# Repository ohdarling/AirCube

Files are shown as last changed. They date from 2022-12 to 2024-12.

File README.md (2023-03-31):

# AirCube 空气检测站

[English Version](README_EN.md)

AirCube 是一个开源的环境状态监测设备，可以监测各种环境状态，例如温度、湿度、二氧化碳浓度、PM 2.5 浓度等，还可以与 Domoticz、Home Assistant 等智能家居系统集成，建立家庭环境数据监测系统。

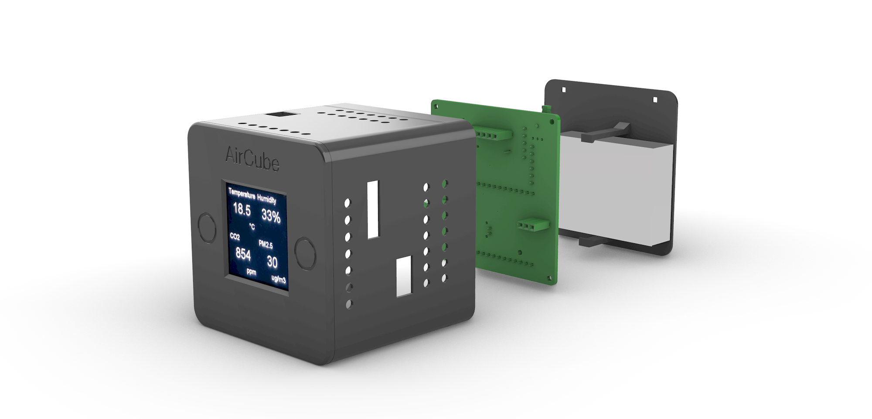
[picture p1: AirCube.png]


## 功能列表

* 概览页面，可以直观查看各种环境数据的当前数值，例如当前温度、湿度、PM 2.5 以及二氧化碳浓度
* 左右键切换传感器详情界面，可以查看具体细分项数值，例如 PM 1，PM 10 等
* 各项数据的历史趋势数据，通过记录过去 12 小时的数据并通过图表展示环境数据的变化趋势
* 特定传感器的详情数据，例如攀藤 PMS5003 可以同时检测 PM 1.0、PM 2.5、PM 10 浓度，在概览页面无法展示完全，就可以在详情页面展示出来
* 设备信息界面，可以展示当前设备的名称、Wi-Fi 连接情况、运行时间等基础信息
* 数据上报能力，可以通过 MQTT 将数据上报到 Domoticz 或 Home Assistant
* 批量部署能力，通过脚本批量部署设备固件

## 更新日志

* 2023.03.31
  * 禁用 MQTT 无法连接时自动重启，防止未配置 MQTT Broker 时 AirCube 定时重启
  
* 2023.02.24
  * 与小米温湿度传感器对比后，BME280 温度校正 -2，湿度 +10
  * 添加重启功能，长按右键 5 秒以上，会重启 AirCube
  * 添加 CO2 传感器校准功能，长按左键 5 秒以上，开启 MH-Z19 或 SenseAir S8 校准功能，校准前请将 AirCube 在室外放置运行 20 分钟以上
  * 使用自定义组件读取 BME280 数据，避免 ESPHome 初始化失败的问题

## 目录结构

* 3D_Model - 设备外壳 3D 模型文件，可以通过 FDM 类型 3D 打印机打印
  * AirCube_Back.stl - 后盖
  * AirCube_Eink.stl - 使用 E-ink 屏幕时的外壳模型
  * AirCube_Eink_Stand.stl - 使用 E-ink 屏幕时的屏幕支架
  * AirCube_LCD.stl - 使用 LCD 屏幕时的外壳模型
  * AirCube_LCD_Stand.stl - 使用 LCD 屏幕时的屏幕支架

* Firmware - 基于 ESPHome 的设备固件，因传感器造型可变化，未编译成二进行，可以自行编译
* Hardware - 包含用于制造 PCB 的 Gerber 文件和原理图

## PCB

PCB 尺寸为 6cm x 6cm，四角安装孔直径为 2mm。

* PCB 正面为屏幕及触摸按钮安装位置。

* PCB 底面为传感器及 NodeMCU 安装位置，目前版本预留了 IR、433MHz 以及电源接头，但并未使用。

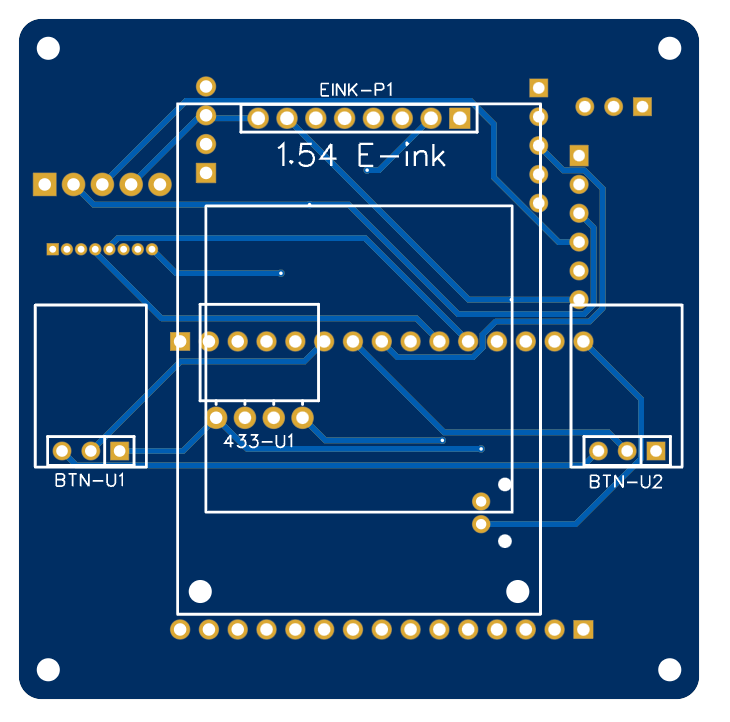
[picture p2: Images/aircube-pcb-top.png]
aircube-pcb-top
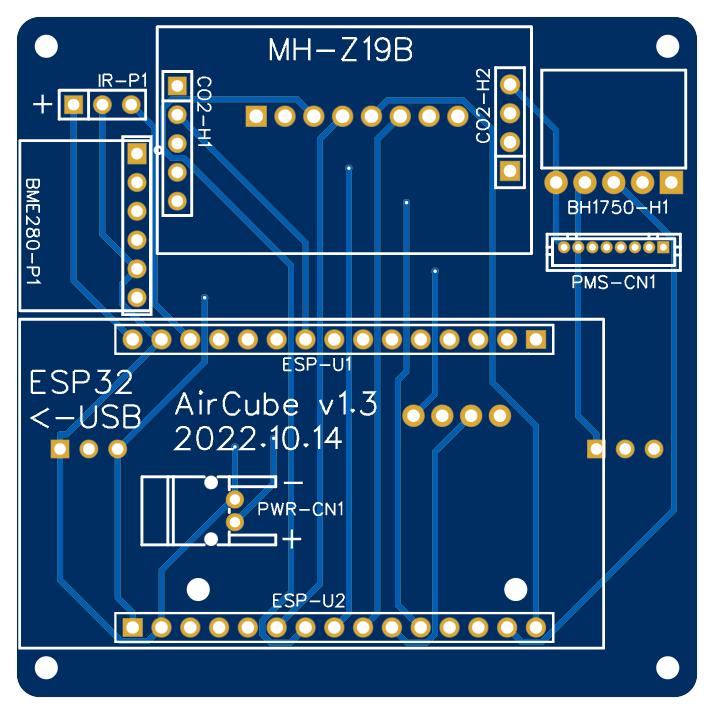
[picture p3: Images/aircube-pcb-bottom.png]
aircube-pcb-bottom


## 元件选型

| 图片 | 类型 | 型号 | 价格（元） | 说明 |
| --- | --- | --- | --- | --- |
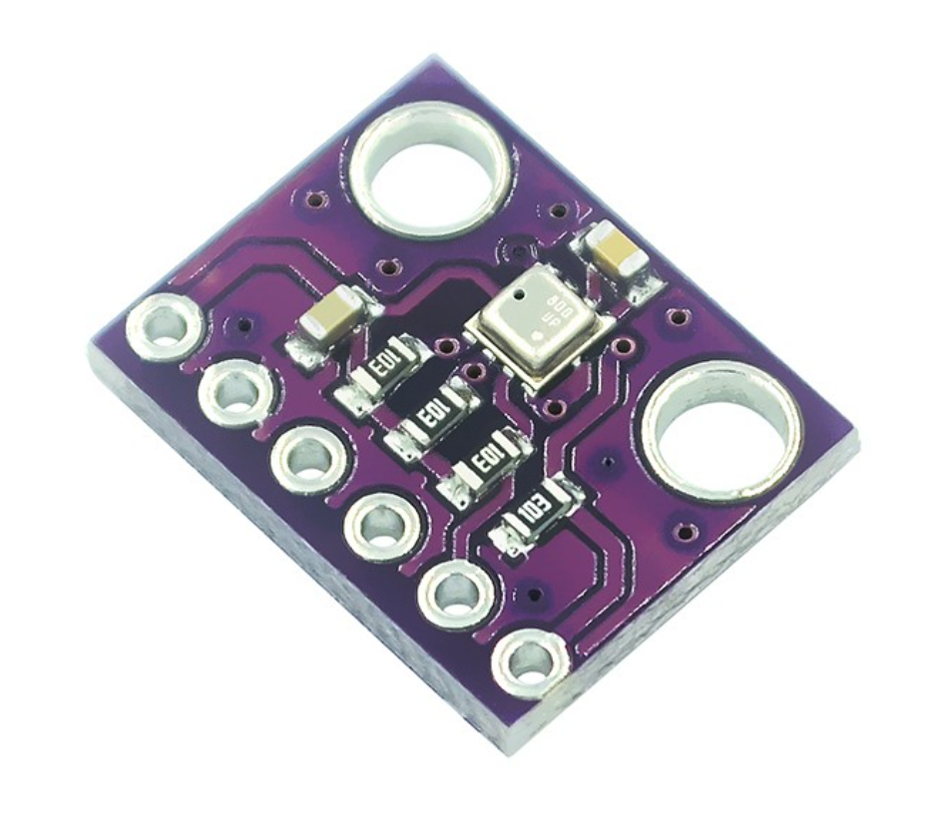
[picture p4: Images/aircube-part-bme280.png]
BME280
|  | 温湿度 | BME280 或 SHT31 | 22 | 其中 BME280 还额外支持压强检测，同时支持这两种传感器主要是因为它们的引脚顺序相同，可以替换使用。 |
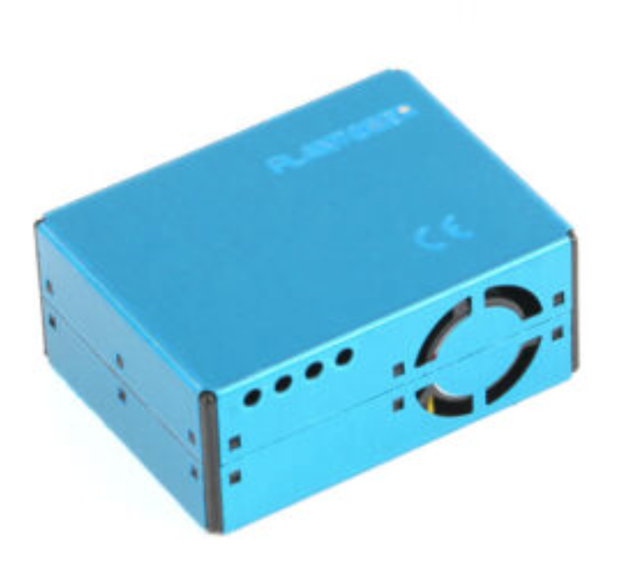
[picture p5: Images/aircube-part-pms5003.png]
PMS5003
|  | 颗粒物浓度 | 攀藤 PMS5003 | 70 | 支持 PM 1.0、PM 2.5、PM 10 三种颗粒物浓度检测，以及 PMS5003ST，额外增加了甲醛浓度检测。另外 PMS7003 虽然同样可以使用，但是因为需要额外转接板，不能直接使用 1.25mm 8P 连接线，因此并不推荐。 |
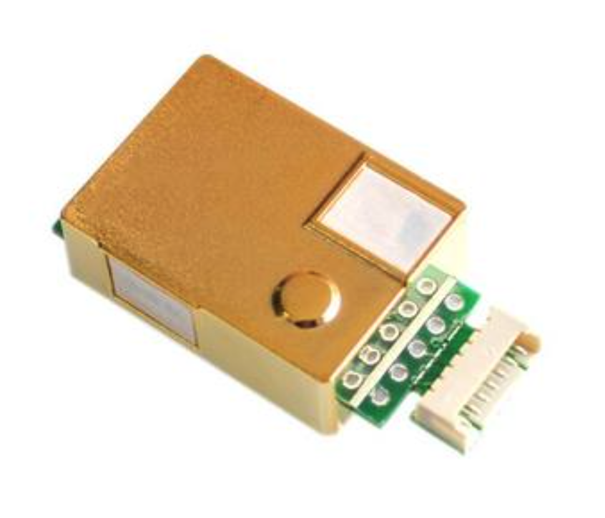
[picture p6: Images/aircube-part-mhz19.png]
MH-Z19B
|  | 二氧化碳浓度 | MH-Z19B | 120 | 可以检测 400-5000 ppm 范围的二氧化碳浓度，当然也可以采用 SenseAir S8 传感器，它们的引脚位置和定义都完全一致。 |
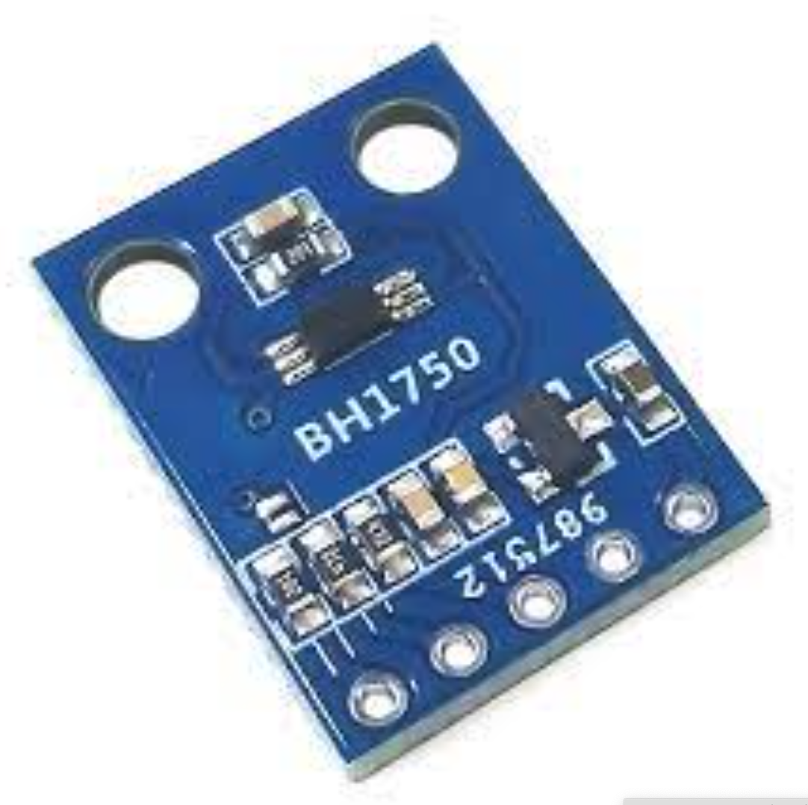
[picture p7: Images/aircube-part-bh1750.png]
BH1750
|  | 光照强度 | BH1750 | 4 | 如果使用光敏电阻还需要额外换算，还是直接采用传感器更简单直接。 |
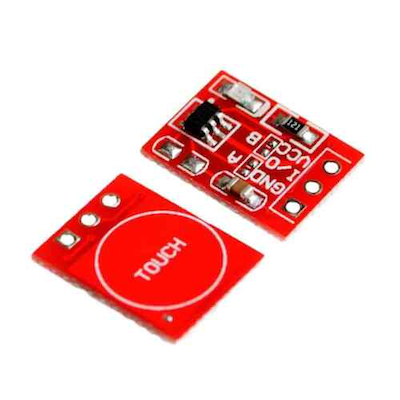
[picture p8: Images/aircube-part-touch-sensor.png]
TTP223
|  | 触摸按钮 | TTP223 | 0.3 | 这个模块触摸感应距离大，可以隔着外壳完成触摸操作，用来切换信息页。 |
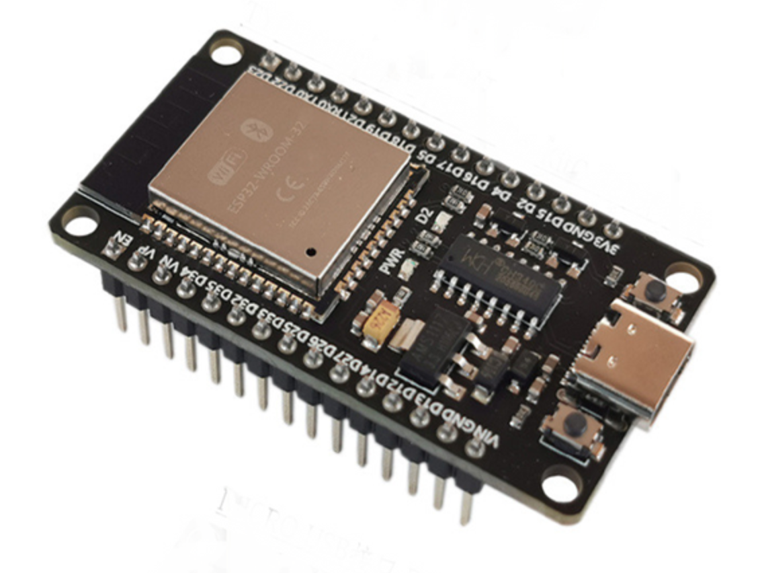
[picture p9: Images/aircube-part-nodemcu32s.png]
NodeMCU-32S
|  | 单片机 | NodeMCU-32S | 22 | 直接选用常见的 NodeMCU-32S 开发板，价格便宜，还可以直接给传感器提供 3.3V 供电。 |
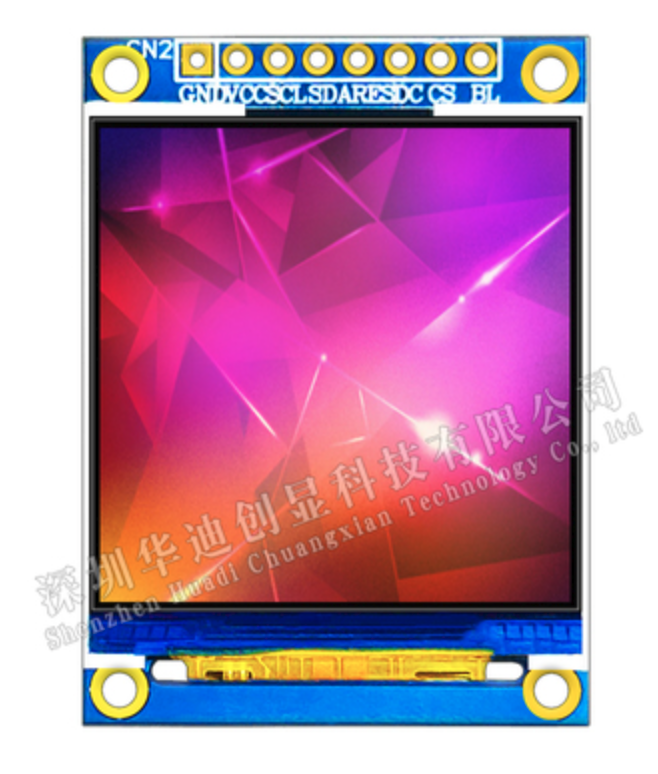
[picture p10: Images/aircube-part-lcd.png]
1.54 LCD
|  | 屏幕 | 1.54 LCD | 20 | 1.54 寸 SPI 接口 IPS 屏幕：分辨率 240x240，主控 ST7789V。 |
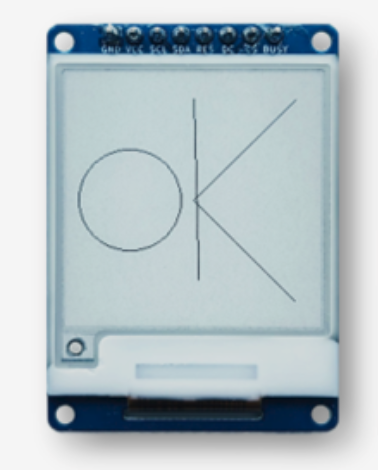
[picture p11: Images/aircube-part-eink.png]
1.54 E-ink
|  | 屏幕 | 1.54 E-ink | 30 | 1.54 寸 SPI 接口 E-ink 屏幕：单色屏，只支持黑白，分辨率 200x200。 |

**注：表格中的价格为淘宝上大致价格，随卖家不同价格也会不太相同。**

## 其他配件

| 配件 | 型号 | 数量 | 用途 |
| --- | --- | ---- | --- |
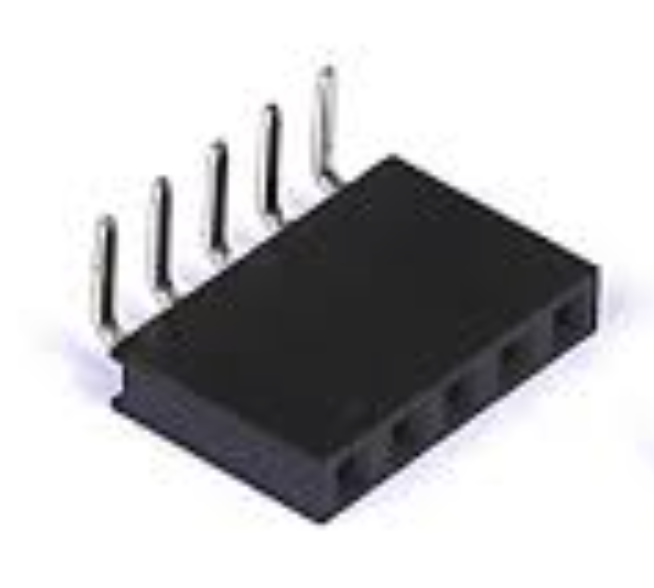
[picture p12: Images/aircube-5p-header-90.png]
aircube-5p-header-90
|  | 弯针 5P 2.54mm 母座 | 2 | 安装 BME280 以及 BH1750 |
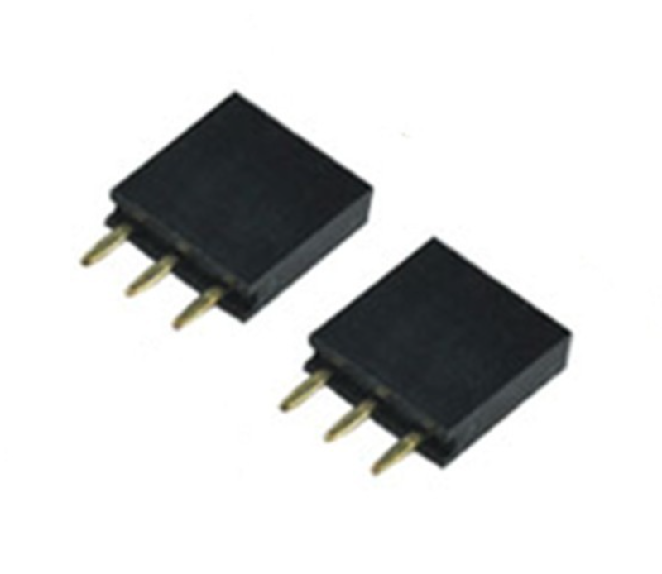
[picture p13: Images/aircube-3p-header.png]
aircube-3p-header
|  | 3P 2.54mm 母座 | 2 | 安装 TTP223 触摸传感器  |
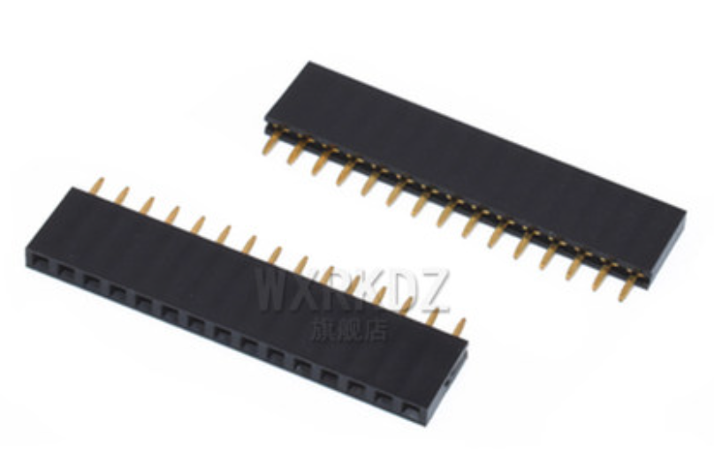
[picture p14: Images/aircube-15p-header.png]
aircube-15p-header
|  | 15P 2.54mm 母座 | 2 | 安装 NodeMCU-32S |
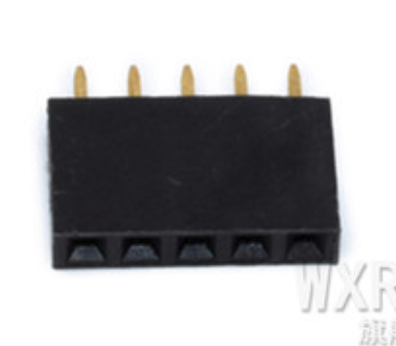
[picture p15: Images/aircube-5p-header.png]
aircube-5p-header
|  | 5P 2.54mm 母座 | 1 | 安装 MH-Z19B |
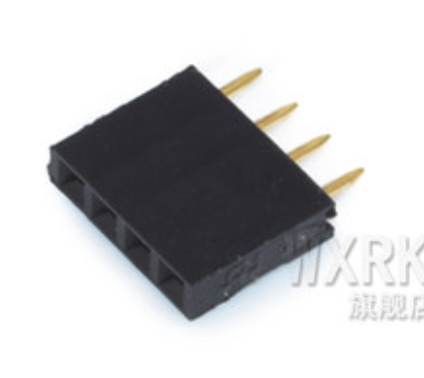
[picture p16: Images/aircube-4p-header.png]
aircube-4p-header
|  | 4P 2.54mm 母座 | 1 | 安装 MH-Z19B |
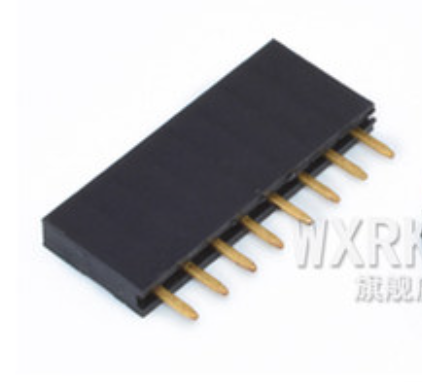
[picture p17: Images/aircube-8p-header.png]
aircube-8p-header
|  | 8P 2.54mm 母座 | 1 | 安装 1.54 寸 LCD |
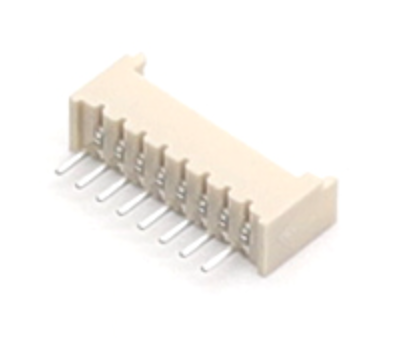
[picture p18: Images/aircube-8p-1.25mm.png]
aircube-8p-1.25mm
|  | 8P 1.25mm 直针座 | 1 | 安装 PMS5003 |
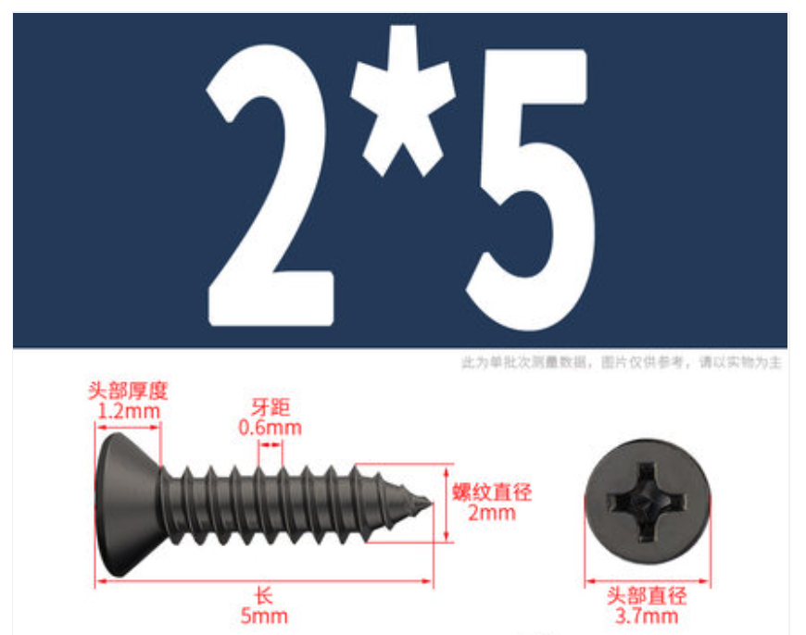
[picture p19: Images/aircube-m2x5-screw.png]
aircube-m2x5-screw
|  | M2*5 沉头自攻螺丝 | 8 | 固定 PCB 以及后盖 |

## 焊接

**建议母座焊接顺序**

1. 5P 弯针 2.54mm 排母
2. 8P 1.25mm 直针座
3. 8P 2.54mm 母座
4. 3Px2 2.54mm 母座
5. 15P 2.54mm 母座
6. 5P 及 4P 2.54mm 母座

其中 BME280 预留位置为 6P，使用弯 5P 母座时，请使用下侧 5P，保留最上针脚留空。

建议参考 [立创开源平台 AirCube](https://oshwhub.com/wandaeda/aircube) 项目中的 PCB 来进行焊接。

## 组装

3D 模型中，外壳和后盖均已预置 M2 螺丝孔，组装时使用 M2*5 自攻螺丝将 PCB 固定在外壳上，再将后盖固定在外壳上即可。

**组装顺序**

1. 将 3D 打印的屏幕支架安装在 PCB 上
2. 将屏幕安装到排母上，并且 M2 螺丝固定在屏幕支架上
3. 将 2 个触摸传感器安装在排母上
4. 将 PMS5003 传感器的连接线连接到 1.25mm 针座上
5. 将 NodeMCU-32S 安装在排母上
6. 将 MH-Z19B 安装在排母上
7. 将 BH1750 安装在排母上
8. 将 PCB 放进外壳中（可以倾斜着放进去），使用 M2 螺丝固定
9. 将 PMS5003 固定在后盖上，有必要可以使用双面胶固定
10. 将后盖使用 M2 螺丝固定在外壳上
11. 将 BME280 在侧面安装在排母上

注意，BME280 预设安装位置为外壳外部，因此需要将其他部件安装完成，装入外壳固定好后，再从侧面将 BME280 插入 5P 母座。

另外，BH1750 的开孔是朝上的，如果需要避免积灰，可以使用透明胶带盖住。

## 编译和烧录固件

Firmware 目录中已经提供了 `build.sh` 脚本用于快速编译及烧录固件，需要本地安装乐鑫 `esptool.py`，另外 `build.sh` 还接受以下参数用于定制可替换部分元件型号或上报数据参数：

* DP - 屏幕类型，st7789v 或 eink，默认 st7789v
* CO2 - 二氧化碳传感器型号，mhz19 或 s8，默认 mhz19
* TEMP - 温湿度传感器型号，bme280 或 sht31，默认 bme280
* DOMOTICZ - 是否启用 Domoticz 支持，enable 或 disable，默认 disable
* ROOM - 当前节点所处房间名称，需要英文字符，例如 livingroom
* IP - 当前节点 IP，建议使用固定 IP，便于后续 OTA 更新固件
* IDX_BH1750，IDX_PM25，IDX_CO2，IDX_TEMP，IDX_PRESSURE，IDX_HOCO - Domoticz 中对应传感器的设备 ID

另外，如果设置了 `IDX_HOCO`，将会将 PM 2.5 传感器类型设置为 PMS5003ST。

另外，`build.sh` 还提供了 `upload` 参数，可以在编译完成后马上烧录固件。

如果所有传感器类型与默认一致，可以直接使用以下命令编译及烧录固件，注意，需要提前将 NodeMCU-32S 连接到电脑上：

`./build.sh upload`

如果需要定制传感器型号，例如将温湿度传感器替换为 sht31，可以使用以下命令：

`TEMP=sht31 ./build.sh upload`

## 为什么会有这个项目

可以参考这篇文章 [超简单 DIY - AirCube 空气检测站](https://xujiwei.com/blog/2022/12/aircube-diy-environment-monitor-station/)。

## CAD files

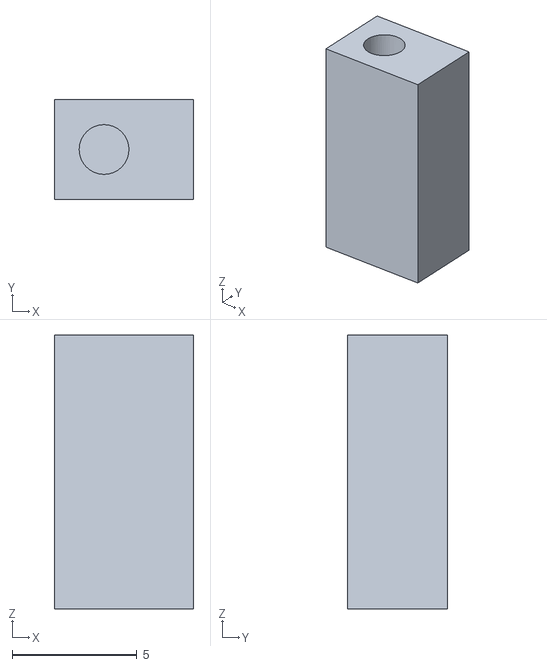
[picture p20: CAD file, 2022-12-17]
3D_Model/AirCube_LCD_Stand.stl
5.60 x 4.00 x 11.0

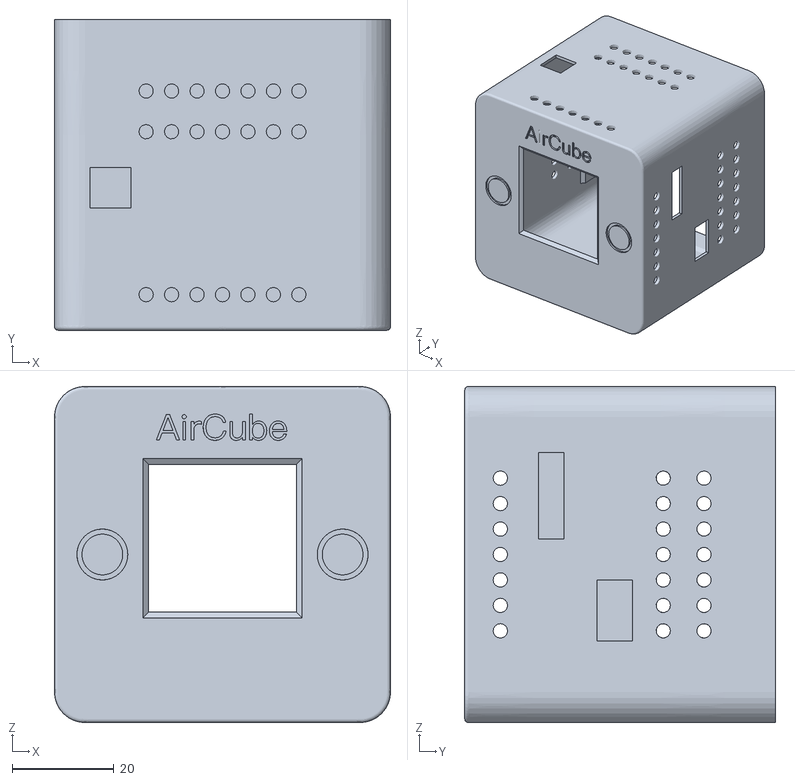
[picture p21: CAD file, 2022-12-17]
3D_Model/AirCube_Eink.stl
66.0 x 61.0 x 66.0

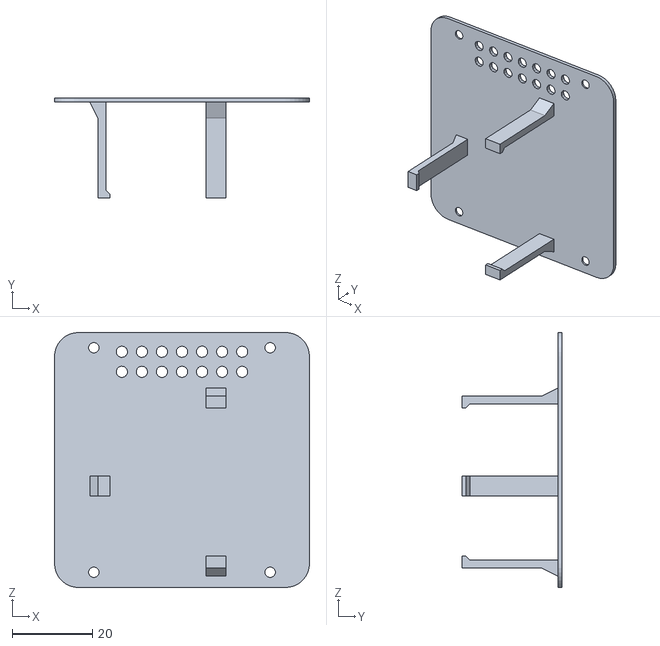
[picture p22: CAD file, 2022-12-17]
3D_Model/AirCube_Back.stl
63.6 x 25.0 x 63.6

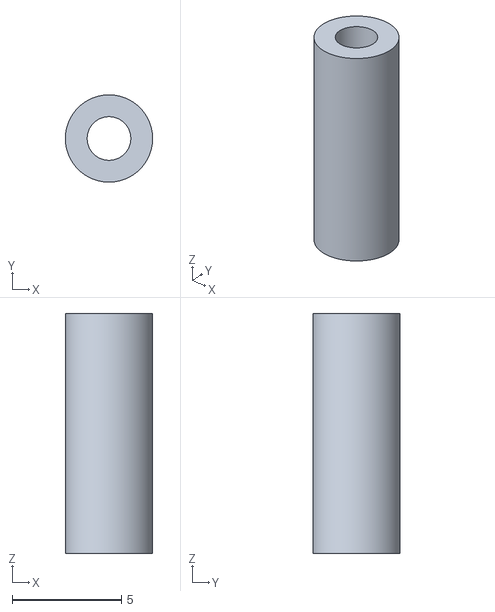
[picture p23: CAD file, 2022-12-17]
3D_Model/AirCube_Eink_Stand.stl
4.00 x 4.00 x 11.0

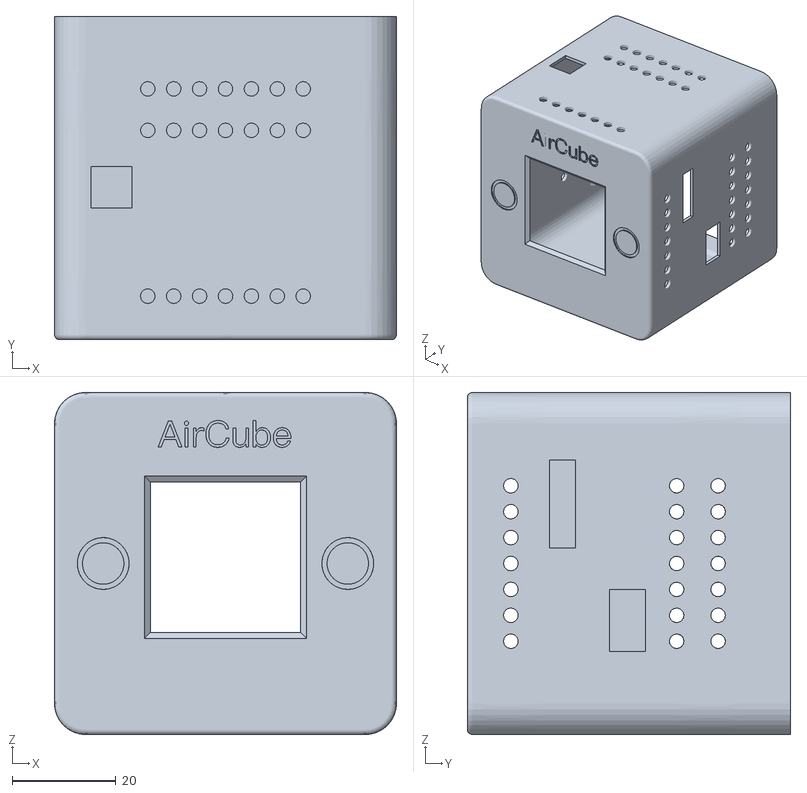
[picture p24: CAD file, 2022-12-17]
3D_Model/AirCube_LCD.stl
66.0 x 62.4 x 66.0

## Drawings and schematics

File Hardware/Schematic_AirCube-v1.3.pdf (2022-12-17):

10 10 11 11 12 12 13 13 14 14 15 15

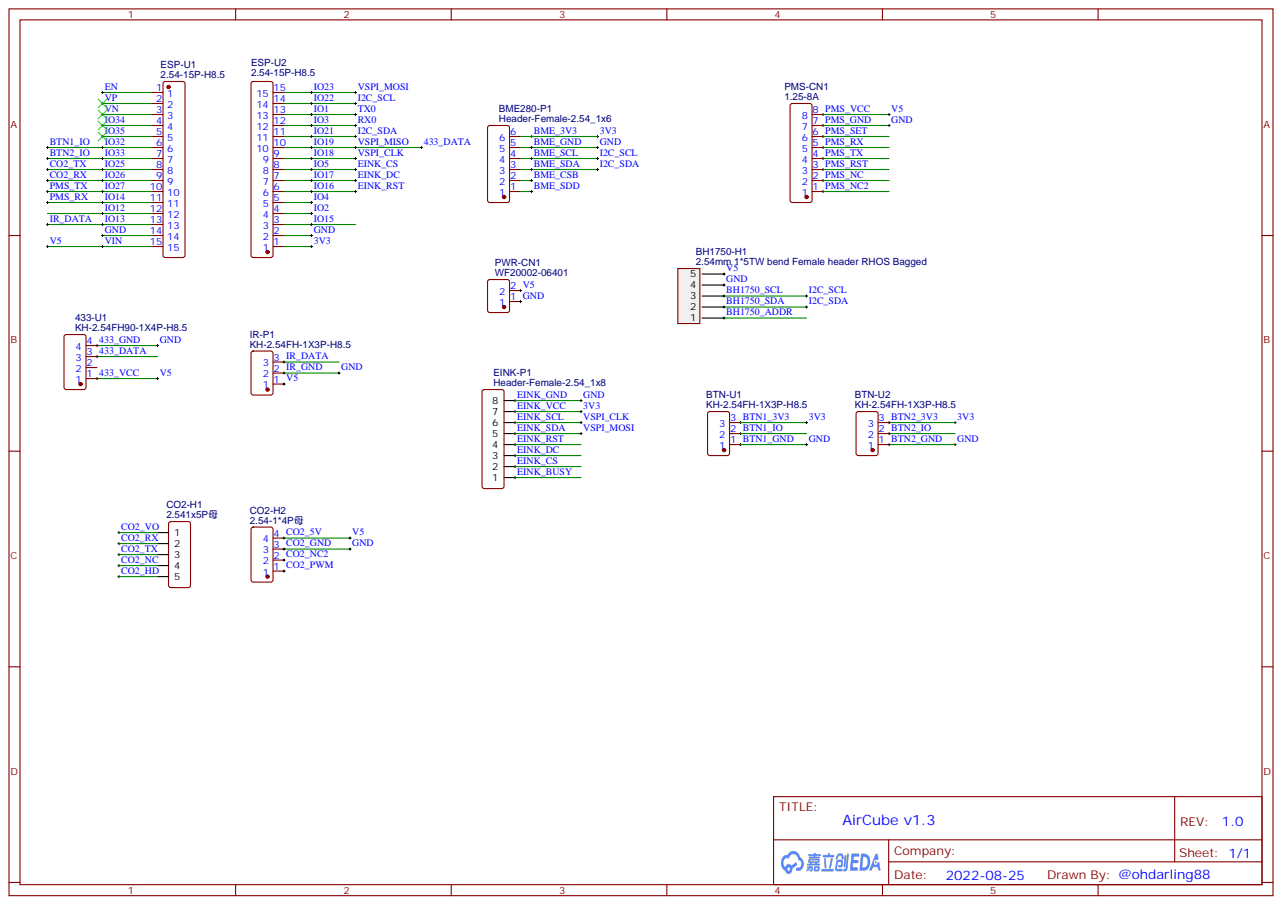
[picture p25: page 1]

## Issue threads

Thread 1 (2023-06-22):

请问怎么编译啊？

SoulLinksIly, 2023-06-22:
小白想做一个这个东西，想知道用什么软件，什么硬件（会ttl），连接什么位置，怎么操作。。。老哥有空做一个教程吗？

ohdarling, 2023-06-22:
1. 硬件可以进去[嘉立创开源平台 AirCube](https://oshwhub.com/wandaeda/aircube) 使用编辑器打开，然后进行 PCB 下单打样，可以领券免费
2. 按 README 中介绍的元件在淘宝上采购，包括 2.54mm 的排母，然后将排母焊接到 PCB 上
3. 软件直接使用 ESPHome，按照 ESPHome 官方文档安装命令行工具之后，clone 本项目，进入 Firmware 目录，支行 esphome run 就可以了

SoulLinksIly, 2023-06-22:
https://github.com/SoulLinksIly/Pic/blob/master/BOM%E5%8F%8A%E9%93%BE%E6%8E%A5.xlsx
老哥，我总结了一下bom，你看各个型号啥的有没有问题，可以添加到你的嘉立创工程的附件里面

SoulLinksIly, 2023-06-22:
对了，板子应该多厚哇？

ohdarling, 2023-06-23:
用 1.6mm 就可以。

ohdarling, 2023-06-23:
看了下 BOM 没啥问题，ESP32 是 30Pin 的，理论上宽度应该是合适的。

SoulLinksIly, 2023-06-24:
ok，感谢！

Closed 2023-06-24.

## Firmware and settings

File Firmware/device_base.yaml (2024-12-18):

esphome:
  name: aircube-${room_name}
  on_boot:
    then:
      - lambda: |-
          setCpuFrequencyMhz(80);
  includes:
    - custom_components/bme280.hpp
  libraries:
    - "Wire"
    - "SPI"
    - "Adafruit Unified Sensor"
    - "Adafruit BusIO"
    - "Adafruit BME280 Library"

esp32:
  board: nodemcu-32s
  framework:
    type: arduino

# Enable logging
logger:

# Enable Home Assistant API
api:
  password: ""
  reboot_timeout: 0s

ota:
  - platform: esphome
    password: ""

captive_portal:

packages:
  # Graph width and height
  # For 1.54 240x240 LCD: 240x120
  # For 1.54 200x200 Eink: 200x100
  # graphsize: !include custom.yaml
  # Font size
  # For 240x240 LCD: 19, 38, 12
  # For 200x200 Eink: 16, 32, 10
  # font: !include components/font.yaml
  sensors: !include sensors.yaml
  binary_sensors: !include binary_sensors.yaml
  text_sensors: !include text_sensors.yaml
  graphs: !include graphs.yaml
  buttons: !include buttons.yaml


substitutions:
  graph_duration: 12h
  font_name: Arial

globals:
  - id: draw_graph
    type: std::function<void(esphome::display::Display & it, const char *title, const char *subtitle, graph::Graph *g, const char *gmax, const char *gmin, const char *add_line)>
    initial_value: |-
      [&](esphome::display::Display & it, const char *title, const char *subtitle, graph::Graph *g, const char *gmax, const char *gmin, const char *add_line) {
        auto scale = screen_scale->value();
        it.print(0, 0, ftitle, title);
        it.print(0, 36*scale, ftitle, subtitle);
        it.graph(0, 80*scale, g);
        it.print(2, 79*scale, fsub, gmax);
        it.print(2, 158*scale, fsub, gmin);
        it.print(0, 172*scale, fsub, "${graph_duration} ago");
        it.print(180*scale, 172*scale, fsub, "now");
        it.print(0, 181*scale, fbody, add_line);
      }

mqtt:
  reboot_timeout: 0s
  broker: !secret mqtt_broker
  log_topic:
    topic: debug
    level: NONE

web_server:
  port: 80

spi:
  clk_pin: 18
  mosi_pin: 23

i2c:
  sda: 21
  scl: 22
  scan: true
  id: busiic

uart:
  - id: uartco2
    tx_pin: 26
    rx_pin: 25
    baud_rate: 9600
  - id: uartpms
    tx_pin: 14
    rx_pin: 27
    baud_rate: 9600

debug:
  update_interval: 5s


remote_transmitter:
  - id: ir_sender
    pin: 13
    carrier_duty_percent: 50
  - id: four33_sender
    pin: 19
    carrier_duty_percent: 100

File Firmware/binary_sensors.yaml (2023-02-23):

binary_sensor:
  - platform: gpio
    pin:
      number: 32
      mode:
        input: true
        pullup: true
    name: "Left Button"
    filters:
      - delayed_on: 10ms
    on_click:
      - min_length: 20ms
        max_length: 500ms
        then:
          - display.page.show_previous: screen
          - component.update: screen
      - min_length: 5s
        max_length: 10s
        then:
          - ${co2_action}: co2sensor
  - platform: gpio
    pin:
      number: 33
      mode:
        input: true
        pullup: true
    name: "Right Button"
    filters:
      - delayed_on: 10ms
    on_click:
      - min_length: 20ms
        max_length: 500ms
        then:
          - display.page.show_next: screen
          - component.update: screen
      - min_length: 5s
        max_length: 10s
        then:
          - lambda: |-
              esp_restart();

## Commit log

2022-12-17 feat: first version
    [AirCube_Back.stl, AirCube_Eink.stl, AirCube_Eink_Stand.stl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]
2023-03-31 disable reboot timeout for mqtt
    [device_base.yaml]
2024-12-18 Fixed ESPHome 2024.12.0 compilation issue
    [device_base.yaml]
